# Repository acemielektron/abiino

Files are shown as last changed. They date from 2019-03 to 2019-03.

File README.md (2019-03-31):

# abiino is a arduino compatible diy board which fits into a breadboard

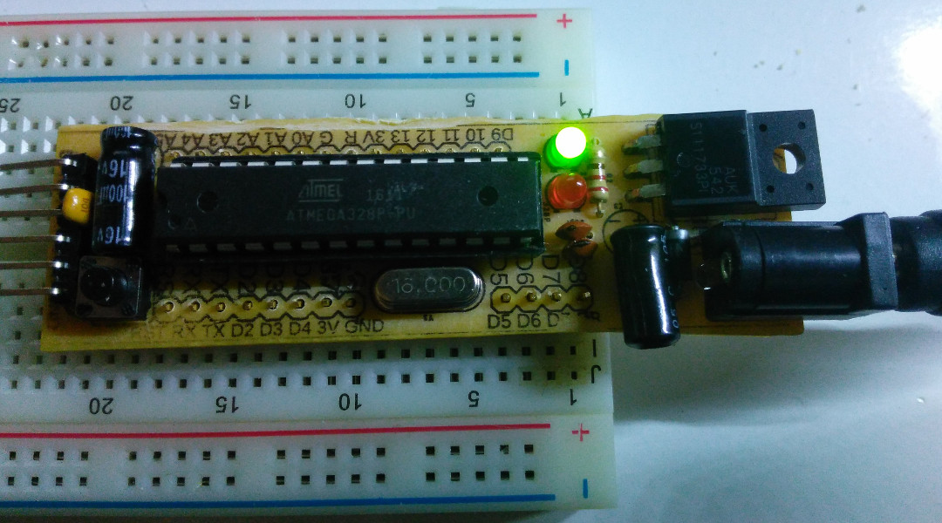
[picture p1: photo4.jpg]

          
<p>abiino is inspired by <a href="https://www.adafruit.com/product/72">DC Boarduino</a> But unlike DC Boarduino abiino is designed as a single sided pcb for easy toner transfer and etching like most diy boards. </p>
<p>And unlike boarduino abiino has a 3.3v linear voltage regulator on board. Unfortunately on board linear voltage regulator S111733PI is not pin compatible with LM78XX so if you want to use abiino with 5v supply with a 7805 you need to change the layout a bit.
<p>Another difference easily seen is abiino does not have an icsp connector. On a single sided pcb making it is as compact as possible is already  challenge enough and i did not want make it any bulkier. Bootloader can be programmed after putting abiino on a breadboard. </p>
<p>I didn't want to make the board any larger than it already is so a 220 ohm resistor connected top 3.3v power supply is shared between green power led and red led connected to D13 so when red led lights green dims a bit.</p>
<p>An important issue to note is soldering breadboard headers in reverse side -although not impossible- is a bit challenging so if you want to build abiino keep that in mind.
<p>And lastly why abiino, abi (short for agabey) in turkish means elder brother. I designed this board for my little brother so it is abiino.

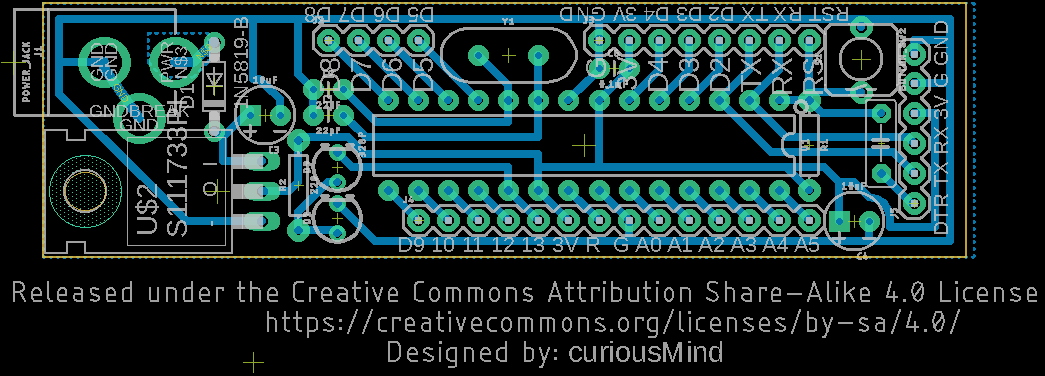
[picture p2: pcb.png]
PCB Layout 
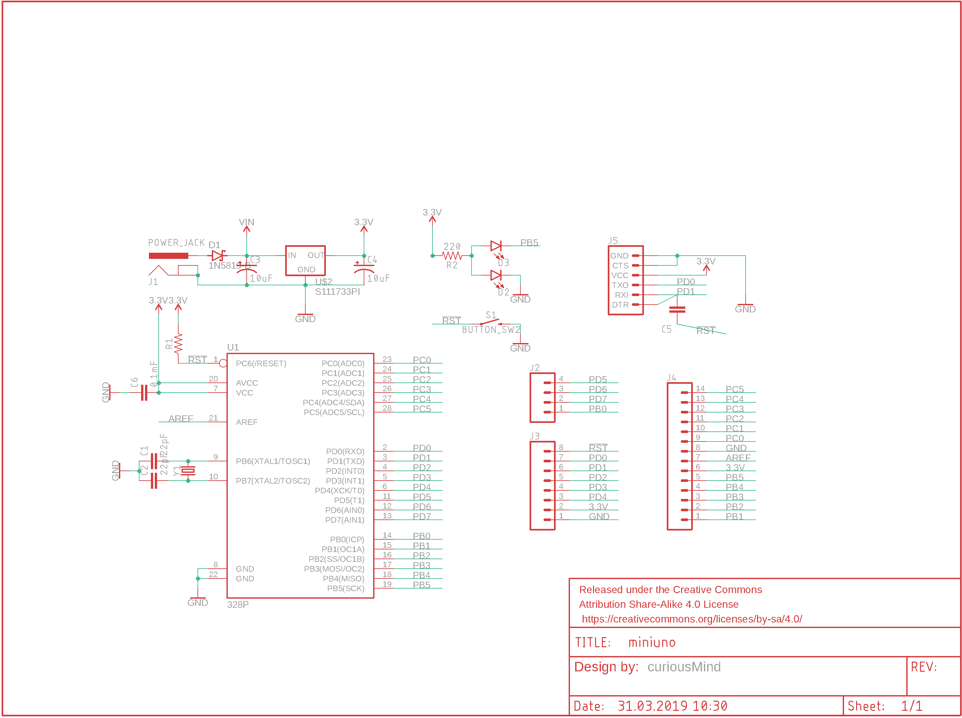
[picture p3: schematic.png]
Schematic

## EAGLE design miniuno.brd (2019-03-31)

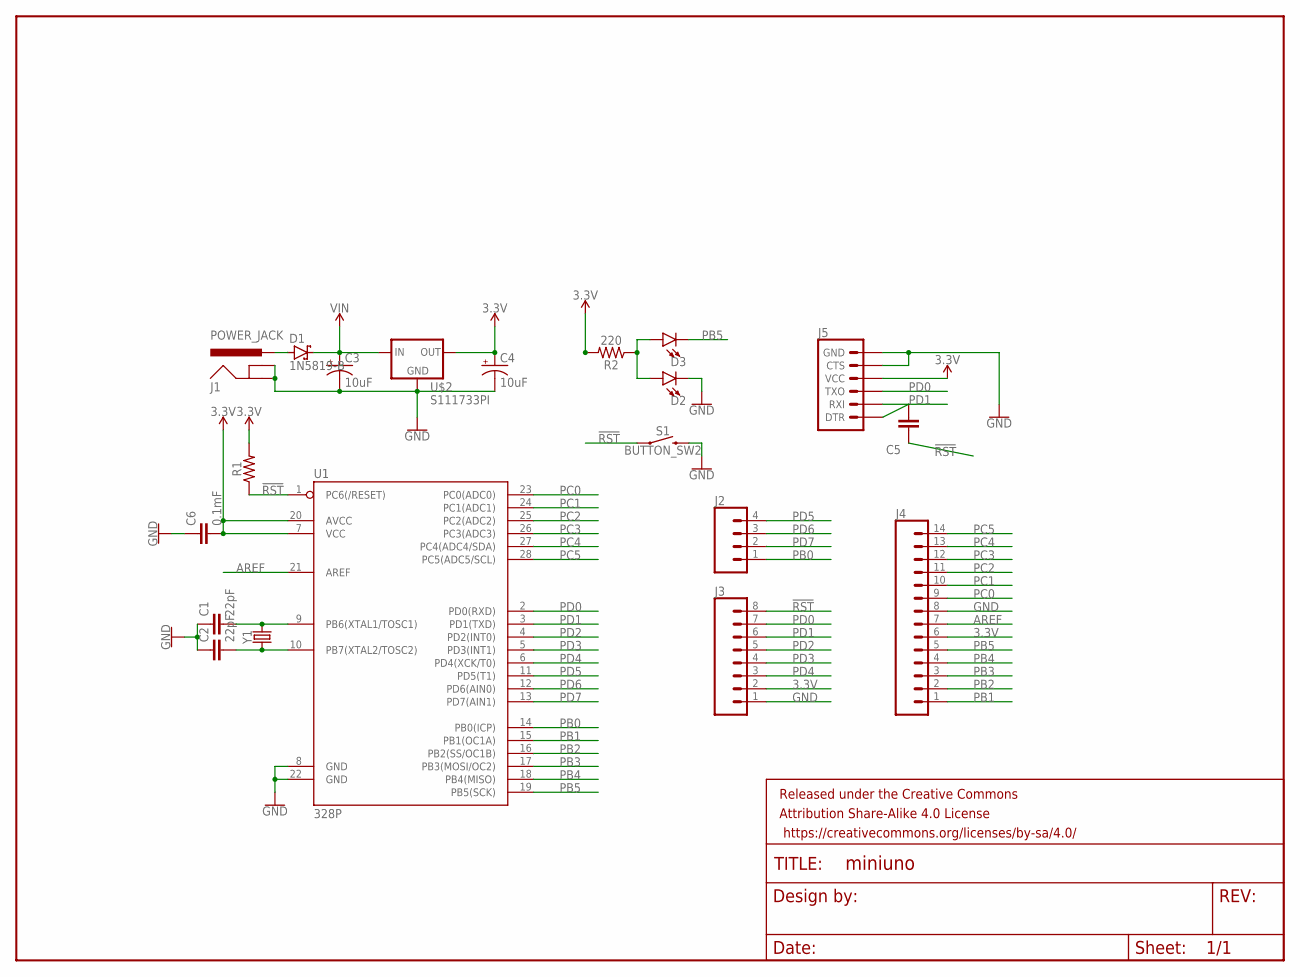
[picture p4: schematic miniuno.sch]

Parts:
C1, C2: 22pF; CAP-PTH-2.54
C3, C4: 10uF; CPOL-RADIAL-2.5MM-5MM-KIT
C5: 0.1uF; C5B2.5
C6: 0.1mF; CAP-PTH-2.54
D1: 1N5819-B; DO41-7.6
D2, D3: LED-3MM-NO_SILK; LED_3MM-NS
FRAME1: FRAME-LETTER; CREATIVE_COMMONS
J1: POWER_JACK; POWER_JACK_PTH
J2: CONN_04; 1X04
J3: CONN_08"; 1X08
J4: CONN_14; 1X14
J5: 6_PIN_SERIAL_TARGETPTH-KIT; 1X06-KIT
R1: AXIAL-0.3
R2: 220; AXIAL-0.3
S1: BUTTON_SW2
U1: 328P; DIP28
U$2: S111733PI; S1117XXPI-TO-220
Y1: CRYSTALPTH-HC49US; HC49US

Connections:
3.3V: C4.1 (+), C6.2, J3.2, J4.6, J5.4 (VCC), R1.P$2 (2), R2.P$2 (2), U1.7 (VCC), U1.20 (AVCC), U$2.OUT
!RST: C5.1, J3.8, R1.P$1 (1), S1.1, U1.1 (PC6(/RESET))
AREF: J4.7, U1.21 (AREF)
GND: C1.1, C2.1, C3.2 (-), C4.2 (-), C6.1, D2.K (C), J1.GND, J1.GNDBREAK, J3.1, J4.8, J5.5 (CTS), J5.6 (GND), S1.2, U1.8 (GND), U1.22 (GND), U$2.GND
unnamed: C1.2, U1.9 (PB6(XTAL1/TOSC1)), Y1.2
unnamed: C2.2, U1.10 (PB7(XTAL2/TOSC2)), Y1.1
unnamed: D1.A, J1.PWR
unnamed: C5.2, J5.1 (DTR)
unnamed: D2.A, D3.A, R2.P$1 (1)
PB0: J2.1, U1.14 (PB0(ICP))
PB1: J4.1, U1.15 (PB1(OC1A))
PB2: J4.2, U1.16 (PB2(SS/OC1B))
PB3: J4.3, U1.17 (PB3(MOSI/OC2))
PB4: J4.4, U1.18 (PB4(MISO))
PB5: D3.K (C), J4.5, U1.19 (PB5(SCK))
PC0: J4.9, U1.23 (PC0(ADC0))
PC1: J4.10, U1.24 (PC1(ADC1))
PC2: J4.11, U1.25 (PC2(ADC2))
PC3: J4.12, U1.26 (PC3(ADC3))
PC4: J4.13, U1.27 (PC4(ADC4/SDA))
PC5: J4.14, U1.28 (PC5(ADC5/SCL))
PD0: J3.7, J5.3 (TXO), U1.2 (PD0(RXD))
PD1: J3.6, J5.2 (RXI), U1.3 (PD1(TXD))
PD2: J3.5, U1.4 (PD2(INT0))
PD3: J3.4, U1.5 (PD3(INT1))
PD4: J3.3, U1.6 (PD4(XCK/T0))
PD5: J2.4, U1.11 (PD5(T1))
PD6: J2.3, U1.12 (PD6(AIN0))
PD7: J2.2, U1.13 (PD7(AIN1))
VIN: C3.1 (+), D1.C, U$2.IN

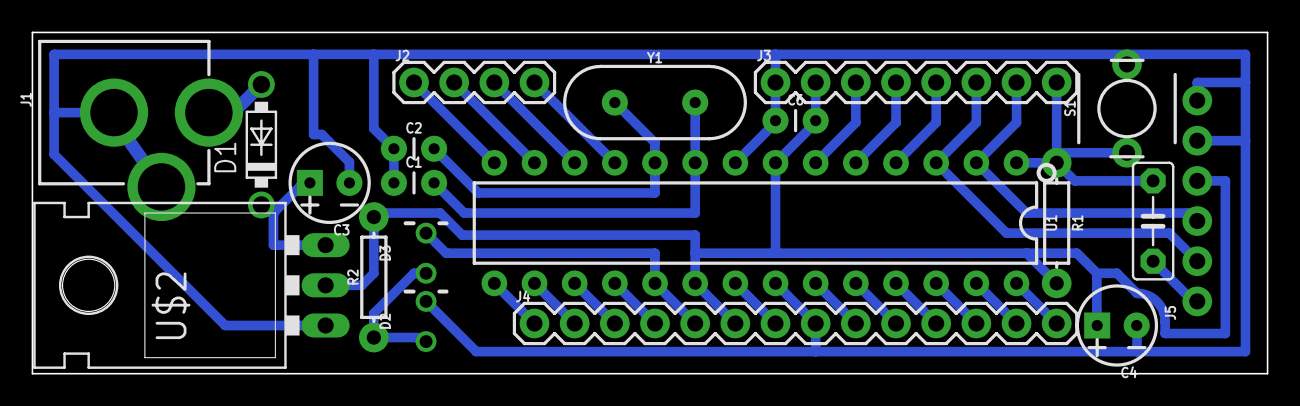
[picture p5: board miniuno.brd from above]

Board: 2 copper layers, 78.1 x 21.6 mm, 21 parts (0 on the bottom side), 30 nets.

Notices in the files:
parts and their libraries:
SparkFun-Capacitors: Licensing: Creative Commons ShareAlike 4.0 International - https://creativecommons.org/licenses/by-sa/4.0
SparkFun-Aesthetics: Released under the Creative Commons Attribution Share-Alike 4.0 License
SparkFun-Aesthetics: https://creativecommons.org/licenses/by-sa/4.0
